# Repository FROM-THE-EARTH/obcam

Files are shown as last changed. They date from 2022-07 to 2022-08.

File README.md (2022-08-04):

# obcam

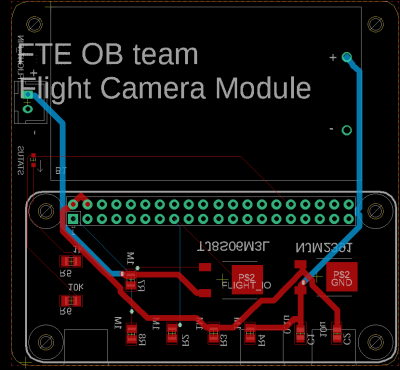
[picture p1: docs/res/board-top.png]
board


`obcam` is the flight camera module and program for the OB team rocket in NSE 2022. See [the site](https://FROM-THE-EARTH.github.io/obcam/) for details.

## Install

After configuration for network connection and installation of `git` and `pip`, run

```bash
python -m pip install git+https://github.com/FROM-THE-EARTH/obcam.git
```

## Install and Activate the flight camera mode

After configuration for network connection and installation of `git`, run

```bash
git clone https://github.com/FROM-THE-EARTH/obcam.git
cd obcam

# After filling out and confirming the glm.py
# See the documentation for detail of the settings.
sudo ./install.sh
```

## Scripts

Scripts in the `scripts` directory may be useful if you want some small operations like installing just `obcam`, activate the flight camera mode, or deactivate the flight camera mode. See [the site](https://FROM-THE-EARTH.github.io/obcam/scripts/) for more information.

**`install.sh`**

This script installs `obcam` and activates the flight camera mode simultaneously.

**`scripts/activate_flightcam.sh`**

This script activates the flight camera mode of the `obcam`. In the flight camera mode, the program of the `obcam` run automatically when booting.

**`scripts/deactivate_flightcam.sh`**

This script deactivates the flight camera mode.

**`scripts/expand_swap.sh`**

This script expands size of the swap file `/var/swap`. In the default setting, size of the swap will be changed to 2048 MB.

**`scripts/install_obcam.sh`**

This script installs the `obcam` module using `pip`. Note that `pip` should be installed before executing this script.

**`scripts/install_pip.sh`**

This script installs `pip`. Note that `pip` could be not installed yet right after the first booting. Thus, this script might be useful in the situation.

**`scripts/uninstall_obcam.sh`**

This script uninstalls the `obcam` module using `pip`.

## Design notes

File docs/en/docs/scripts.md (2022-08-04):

# Scripts

There are some executable shell scripts in the repository. You can run the scripts if downloading the repository to local. In many cases, you should execute the scripts as the root user.

## `install.sh`

This script installs `obcam` and activates the flight camera mode simultaneously. This script is executed using other scripts below, so you should not delete other scripts. This script requires network connection.

```bash
sudo ./install.sh
```

## `scripts/activate_flightcam.sh`

This script activates the flight camera mode.

```bash
sudo scripts/activate_flightcam.sh
```

## `scripts/deactivate_flightcam.sh`

This script deactivates the flight camera mode.

```bash
sudo scripts/deactivate_flightcam.sh
```

**`scripts/expand_swap.sh`**

This script expands size of the swap file `/var/swap`. In the default setting, size of the swap will be changed to 2048 MB.

```bash
sudo scripts/expand_swap.sh
```

You can change the swap size specifying value of the environment variable `SWAPSIZE`:

```bash
# Change to 1024 MB.
sudo SWAPSIZE=1024 scripts/expand_swap.sh
```

## `scripts/install_obcam.sh`

This script just installs `obcam` using `pip`, but doesn't activate the flight camera mode. This script requires network connection.

```bash
sudo scripts/install_obcam.sh
```

## `scripts/install_pip.sh`

This script installs `pip`. This script requires network connection.

```bash
sudo scripts/install_pip.sh
```

## `scripts/uninstall_obcam.sh`

This script uninstalls `obcam` using `pip`.

```bash
sudo scripts/uninstall_obcam.sh
```

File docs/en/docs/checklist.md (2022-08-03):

# Checklist

## Advance Preparation

- [ ] Make more than 2 SD cards Raspberry Pi OS Lite (32bit), referencing [the section](./setup.md#setup-of-the-os).
- [ ] Connect a monitor and keyboard to the Raspberry Pi.
- [ ] Boot the Raspberry Pi.
- [ ] Configure the keyboard setting.
- [ ] Configure the system settings using `raspi-config`, referencing [the section](./setup.md#essential-system-setttings-in-raspi-config).
    - [ ] WiFi setting for network connection.
    - [ ] Enabling legacy camera support.
- [ ] Install `git`:
    ```bash
    sudo apt update
    sudo apt install -y git
    ```
- [ ] Clone the `obcam` repository:
    ```bash
    git clone https://github.com/FROM-THE-EARTH/obcam.git
    cd obcam
    ```
- [ ] Confirm `glm.py` in the repository and change the content if necessary.
    ```bash
    # Confirm the content
    less glm.py

    # Change the content
    vi glm.py
    ```
- [ ] Install `obcam` and activate the flight camera mode:
    ```bash
    sudo ./install.sh
    ```
- [ ] Reboot the system:
    ```bash
    sudo reboot
    ```
- [ ] Check the LED is blinking (which means the program waits for connection of a flight pin). If the LED is blinking, then all preparation is done. Otherwise, connect a monitor and keyboard to the Raspberry Pi and view log output from the program. For more log output, you can change value of the parameter `log_level` to `logging.DEBUG` in `/usr/local/src/obcam/glm.py`:
    ```bash
    sudo vi /usr/local/src/obcam/glm.py

    # in the file
    #
    # ...
        - log_level=logging.INFO,
        + log_level=logging.DEBUG,
    ```

## In a rocket range

- [ ] Connect a Raspberry Pi which is setup already, flight pin cable, and 9V battery to the board.
- [ ] Confirm the LED is blinking. If the flight pin is already connected, the LED doesn't blink but is turned off. If the LED is being turned off dispite the flight pin is disconnected, connect a monitor and keyboard to the Raspberry Pi and view log output from the program. If the camera is not detected, try to enable legacy camera support referencing [the section](./setup.md#enabling-legacy-camera-support) and reconnect camera cable.
- [ ] If the program is executed successfully, put the board in to a plastic bag.
- [ ] Close up the zipper of the plastic bag using curing tape.
- [ ] Put the plastic bag in to another platic bag and close up the zipper again.
- [ ] Put some block of styrofoam in to the nose corn.
- [ ] Put the camera in to the nose cone and fix the camera using curing tape.
- [ ] Put the plastic bag in to the nose corn.
- [ ] Connect the flight pin cable to the cable for the main board.
- [ ] Connect the flight pin.
- [ ] If you need, activate certain [command](./flightcam.md#commands).

## After collecting the body

- [ ] Remove the SD card from the Raspberry Pi and clean the SD card.
- [ ] Insert the SD card to your PC.
- [ ] Extract the movie file and log file from the SD, referencing [the section](./flightcam.md#extract-data-from-sd-cards).
- [ ] Confirm the movie and log.

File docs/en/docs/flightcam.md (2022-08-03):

# Flight Camera

## Assembly

If you finish activation of the flight camera mode referencing the [page](./setup.md), you can go forward to the next step, assembly of the module. In this section, details of components and their assembly are explained.

### Board Overview

The figure below is a board of the flight camera module. The module has some features:

- **Status LED** tells status of the program in the flight camera mode.
- **XH pin socket** is the interface to a flight pin.

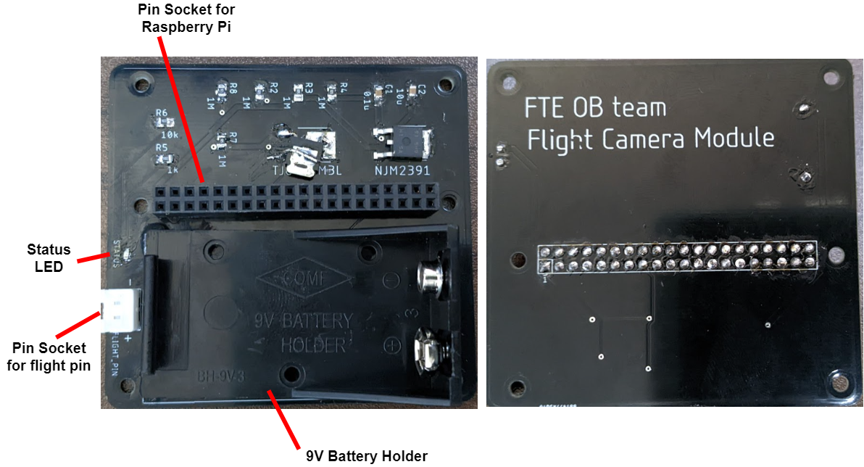
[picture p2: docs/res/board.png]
board


### Raspberry Pi Zero

The below picture is of a Raspberry Pi Zero. Raspberry Pi Zero has 40 of GPIO pins and some interfaces, e.g. HDMI, USB and Raspberry Pi Camera. It is recommended to connect to a monitor and keyboard when you setup a Raspberry Pi.

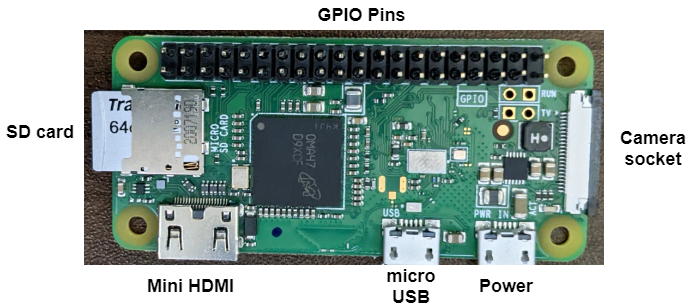
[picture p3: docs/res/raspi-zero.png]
raspi-zero


!!!info "Setup a Raspberry Pi Zero without a monitor"
    There is a way to setup a Raspberry Pi Zero without a monitor, but it is not recommended because it has more steps for setup and you cannot get any signals if there is something wrong.

### Connecting a Camera

1. Prepare a Raspberry Pi Camera and flexible cable for Raspberry Pi Zero. Note that the cable for Raspberry Pi Zero is not same as one of Type A or B.
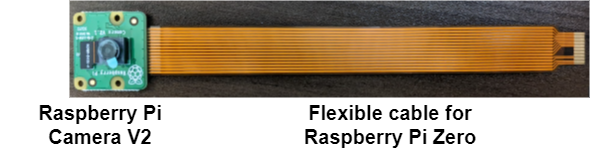
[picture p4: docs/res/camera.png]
camera
   

2. Raspberry Pi Zero has a camera socket and its stopper (black part of the bottom). Put the stopper down to insert the cable.<br>
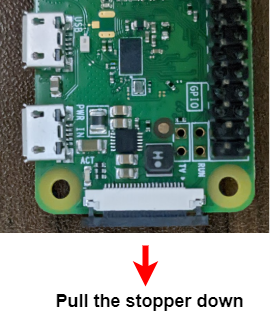
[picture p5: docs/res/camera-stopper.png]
camera-stopper
   

3. Insert the cable into the socket and put the stopper in to fix the cable.
   connecting-camera

### Board Assembly

1. Insert GPIO pins into the pin socket on the board.
2. Connect a flight pin cable to the XH socket.
3. Put in a 9V battery to the battery holder. And then, the Raspberry Pi starts to boot.
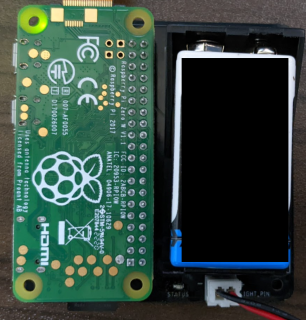
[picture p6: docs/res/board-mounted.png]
board-mounted


## Flow of the program

### Operations

1. Program starts at booting.
2. Status LED blinks until the flight pin is connected.
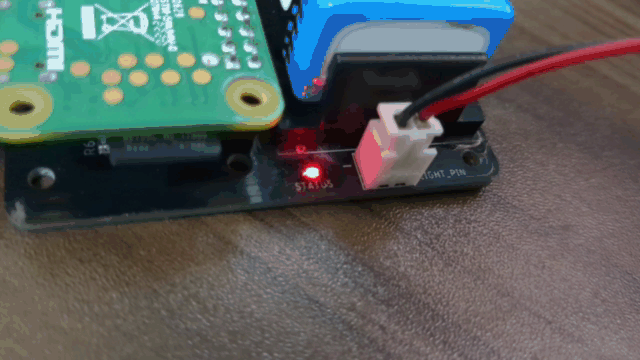
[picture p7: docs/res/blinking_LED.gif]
blinking_LED
    
3. After the flight pin is connected, the status LED is turned off until the flight pin is to be disconnected.
4. When the flight pin is disconnected, the stauts LED is turned on and recording starts.
5. Observing if any commands occur while recording.
6. When the time elapses to the value of `timeout` or a command is detected, recording stops.
7. If the setting is configured, the system is automatically shutted down.

### Commands

There are some commands for users to operate state of the program.

| name | condition | description |
|:---:|:---:|:---|
| NULL | --- | No commands are activated. |
| RESTART | Flight pin connection in more than `threshold_restart` seconds. | Program will stop recording and restart from the begging. Parameter `threshold_restart` can be set in `glm.py`, defaults 5 seconds. |
| EXIT | Flight pin connection in less than `threshold_exit` seconds, and then disconnection in more than `threshold_exit` seconds. | Program will stop recording and exit immediately without shutting down. Parameter `threshold_exit` can be set in `glm.py`, defaults 2 seconds. |

### Flowchart

Characters in red in the flowchart below are parameters in the application. For more information, see [Setting](./setting.md).

flowchart

## Outputs

The flight camera application outputs two kinds of files, one is a movie file and the other is a log file.

### Movie Files

Movie files are the main outputs of the application. You can specify path to a movie file before activating the flight camera mode, by writing the path to `glm.py`. See [Setting](./setting.md#filemov) for details.

In the default setting, the format of movie files is `.h264`. This format could not be played in your favorite movie player. It is recommended using [VLC media player](https://www.videolan.org/vlc/index.ja.html) for playing the format of movies. However, there can exist block noise when playing `.h264` videos, so it might be ideal that you convert `.h264` format to `.mp4` (which is possible using like [the site](https://anyconv.com/ja/h264-to-mp4-konbata/)).

### Log Files

Log files are useful to analysis state of the application, especially during debug. You can also specify path to a log file before activating the flight camera mode. See [Setting](./setting.md#filelog) for more information.

The log level of the application can be changed in `glm.py`. You can specify `logging.DEBUG` as parameter `log_level` to output verbose log for debugging.

Below is an example of the log output.

```log
[2022-08-02 03:59:53,126] [INFO] Start the Flight camera mode. Setting; glm_name: main, timeout: 210.0, pin_flight: 22, pin_led: 12, file_mov: mov-220802-035953.h264, file_log: mov-220802-035953.log, parent_dir: None, resolution: (1920, 1080), framerate: 30, interval: 0.1, led_blink_freq: 2.0, log_level: 20, check_waiting_time: False
[2022-08-02 03:59:53,218] [INFO] Waiting a flight pin to be connected...
[2022-08-02 04:00:01,074] [INFO] Detected that the flight pin was connected.
[2022-08-02 04:00:01,075] [INFO] Wating the flight pin to be disconnected...
[2022-08-02 04:00:03,034] [INFO] Detected that the flight pin was disconnected.
[2022-08-02 04:00:03,034] [INFO] Start recording.
[2022-08-02 04:03:33,151] [INFO] Stop recording.
```

### Extract data from SD cards

Your Windows couldn't recognize data in SD cards used in Raspberry Pi because of difference of formats. Thus, you should do unusual operation to extract the data.

**Use 3rd-party applications**

There are some applications that can read data in ext file systems like Raspberry Pi. You can pick favorite one from the list below:

- [extFS for Windows](https://www.paragon-software.com/business/extfs-for-windows/)
- [Linux Reader](https://www.diskinternals.com/linux-reader/)

**Transfer via HTTP**

If you have another Raspbery Pi, which is not broken and whose WiFi setting (tethering is recommended) is already done, you can insert the SD card to the Raspberry Pi and transfer data via HTTP communication.

1. Enable network connection of a Raspberry Pi. If network setting is not done yet, configure referencing [the section](./setup.md#wifi-setting).
2. Confirm IP address of the Raspberry Pi:
    ```bash
    ip a

    # Example of output
    # ...
    # 2: wlan0: <BROADCAST,MULTICAST,UP,LOWER_UP> mtu 1500 qdisc mq state UP group default qlen 1000
    # link/ether ff:ff:ff:ff:ff:ff brd ff:ff:ff:ff:ff:ff
    # inet 192.168.x.x/24 brd 192.168.x.255 scope global noprefixroute eth0
    #       ↑ this is the IP address.
    ```
3. Change the working directory to directory which has files you want to send.
    ```bash
    cd [/path/to/directory]
    # e.g. cd /
    ```
4. Start HTTP server specifying the IP address.
    ```bash
    # Change the IP address to one of your environment.
    sudo python -m http.server -b 192.168.x.x 80
    ```
5. Open a browser in your smart phone or PC in the same network as the Raspbery Pi.
6. Enter the URL:
    ```
    # Change the IP address to one of your environment.
    # Change the file name to one you want to send.
    http://192.168.x.x/[file_name]
    ```

**Transfer via SSH**

If you have another Raspbery Pi, which is not broken and whose WiFi setting (tethering is recommended) is already done, you can insert the SD card to the Raspberry Pi and transfer data via SSH communication.

1. Enable network connection of a Raspberry Pi. If network setting is not done yet, configure referencing [the section](./setup.md#wifi-setting).
2. Enable the SSH server:
    ```bash
    sudo raspi-config
    # 1. Select [Interface Options]
    # 2. Select [SSH]
    # 3. Select [Yes]
    ```
3. Confirm IP address of the Raspberry Pi:
    ```bash
    ip a

    # Example of output
    # ...
    # 2: wlan0: <BROADCAST,MULTICAST,UP,LOWER_UP> mtu 1500 qdisc mq state UP group default qlen 1000
    # link/ether ff:ff:ff:ff:ff:ff brd ff:ff:ff:ff:ff:ff
    # inet 192.168.x.x/24 brd 192.168.x.255 scope global noprefixroute eth0
    #       ↑ this is the IP address.
    ```
4. Open a terminal (PowerShell in Windows) in your PC in the same network as the Raspberry Pi, and run the command:
    ```bash
    # Change the IP address to one of your environment.
    # Change paths in remote and local to ones you want to send and received.
    scp obteam@192.168.x.x:/path/to/file /local/path/to/file

    # Enter passphrase of the Raspberry Pi.
    ```

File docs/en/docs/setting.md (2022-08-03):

# Setting

## gileum file

gileum files are kinds of setting files of the application. In a gileum file, an object of the `OBCamGileum` should be created. The default gileum file is prepared [in the repository](https://github.com/FROM-THE-EARTH/obcam/blob/main/glm.py). If necessary, you can change the content of the gileum file and apply the setting when executing the flight camera application.

## `OBCamGileum`

This class is the setting class of the application. You should only instantiate the class giving the parameters below.

### `timeout`

Length of recording time.

### `pin_flight`

Pin number for a flight pin, defaults `22`.

### `pin_led`

Pin number for a status LED, defaults `12`.

### `file_mov`

Path to new video file, defaults `None`.

### `file_log`

Path to new log file, defaults `None`.

### `parent_dir`

Path to the parent directory of output files, defaults `None`. If a specfied directory doesn't exist, the program automatically create the repository.

### `resolution`

Resolution of the video to be recorded, defaults `(1920, 1080)`. You cannot make the value greater than the default value, because `(1920, 1080)` is about maximum value.

### `framerate`

Framerate of the video to be recorded, defaults `30`. You cannot make the value greater than the default value, because `30` fps is about maximum value.

### `interval_recording`

Wating time for recording, `0.1`.

### `led_blink_freq`

Frequency of LED blinking, defaults `2.`.

### `log_level`

Log level used in the application, defaults `logging.INFO` (`20`).

### `check_waiting_time`

If making log outputs during waiting time for disconnection of the flight pin or not, defaults `False`.

### `interval_waiting_time`

Interval of waiting time until the flight pin is disconnected, defaults `0.1`. This parameter doesn't valid when the parameter `check_waiting_time` is `False`.

### `shutdown_after_recording`

If shutting down the system after recording or not, defaults `True`.

### `interval_watching`

Interval of watching processes in other threads, defaults `0.1`.

### `threshold_restart`

Time threshold of waiting time to activate the command `RESTART`, defaults `5.`. The command `RESTART` is activated if the flight pin is connected again for more than `threshold_restart` seconds during recording.

### `threshold_exit`

Time threshold of waiting time to activate the command `EXIT`, defaults `2.`. The command `EXIT` is activated if the flight pin is connected for less than `threshold_exit` seconds and disconnected again for more than `threshold_exit` seconds during recording.

## Examples

```python
import logging
from obcam import OBCamGileum

glm = OBCamGileum(
    # Make the timeout shorter for tests.
    timeout=10,

    # Change path to the movie file.
    file_mov="test.h254",

    # Change path to the log file.
    flie_log="test.log",

    # Set the parent directory of the output files.
    parent_dir="/obcam-out"

    # Make the frequency smaller.
    led_blink_freq=1.,

    # Make verbose log outputs for tests.
    log_level=logging.DEBUG,

    # Observe waiting time until the flight pin is disconnected.
    check_waiting_time=True,

    # Use the default settings.
    # To use defualt values, you don't have to give corresponding arguments.
    pin_flight=22,
    pin_led=12,
    resolution=(1920, 1080),
    framerate=30,
    interval_recording=0.1,
    interval_waiting_time=0.1,
    shutdown_after_recording=True,
    interval_watching=0.1,
    threshold_restart=5.,
    threshold_exit=2.,
)
```

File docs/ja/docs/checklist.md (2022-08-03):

# チェックリスト

## 事前準備

- [ ] [こちらのセクション](./setup.md#os)を参考にして Raspberry Pi OS Lite (32bit) のイメージが書き込まれた SD カードを3個以上準備しておきます。
- [ ] Raspberry Pi にモニターとキーボードを接続します。
- [ ] Raspberry Pi を起動します。
- [ ] キーボード設定を行います。
- [ ] [こちらのセクション](./setup.md#raspi-config)を参考にして `raspi-config` を使ったシステム設定を行います。
    - [ ] WiFi 設定
    - [ ] 「legacy camera support」の有効化
- [ ] `git` のインストールを行います。
    ```bash
    sudo apt update
    sudo apt install -y git
    ```
- [ ] `obcam` リポジトリのダウンロードを行います。
    ```bash
    git clone https://github.com/FROM-THE-EARTH/obcam.git
    cd obcam
    ```
- [ ] リポジトリ下の `glm.py` を確認し、必要があれば編集します。
    ```bash
    # Confirm the content
    less glm.py

    # Change the content
    vi glm.py
    ```
- [ ] `obcam` のインストールとフライトカメラモードの有効化を行います。
    ```bash
    sudo ./install.sh
    ```
- [ ] Raspberrry Pi を再起動します。
    ```bash
    sudo reboot
    ```
- [ ] LED の点滅を確認します（LED の点滅はフライトピンの接続待ち状態を意味します）。もし LED が点滅している場合は全ての事前準備が完了した状態です。そうでなければ、モニターとキーボードを Raspberrry Pi に接続し、プログラムのログ出力を確認してください。詳細なログ出力を行いたい場合は `/usr/local/src/obcam/glm.py` 内の `log_level` パラメータを `logging.DEBUG` に変更します：
    ```bash
    sudo vi /usr/local/src/obcam/glm.py

    # in the file
    #
    # ...
        - log_level=logging.INFO,
        + log_level=logging.DEBUG,
    ```

## 射場にて

- [ ] セットアップされた Raspberrry Pi とフライトピン用ケーブル、9V バッテリーを基板に接続します。
- [ ] ステータス LED の点滅を確認します。もしフライトピンが接続されている場合は、LED は点滅せず消灯状態になります。フライトピンが接続されているにも関わらず LED が消灯している場合は、モニターとキーボードを Raspberrry Pi  に接続してログ出力を確認してください。もしカメラの接続が検知されていなかった場合は、[こちらのセクション](./setup.md#legacy-camera-support)を参考にして「legacy camera support」を有効化するとともに、カメラ用ケーブルを再接続してください。
- [ ] プログラムが正常に起動している場合、基板をジップロックに入れます。
- [ ] 養生テープでジッパー部分を閉めます。
- [ ] もう1つのジップロックに基板を入れたジップロックを入れ、再度養生テープでジッパー部分を閉めます。
- [ ] 発泡スチロールのブロックをノーズコーンに入れます。
- [ ] カメラをノーズコーン内に入れ、養生テープで固定します。
- [ ] 基板を入れたジップロックをノーズコーンに入れます。
- [ ] カメラ基板から出ているフライトピン用ケーブルをメイン電装のフライトピン用ケーブルと接続します。
- [ ] フライトピンを接続します。
- [ ] 必要があれば[コマンド](./flightcam.md#_8)を実行します。

## 回収後

- [ ] SD カードを Raspberrry Pi から取り出し汚れをふき取ります。
- [ ] PC に SD カードを差し込みます。
- [ ] [こちらのセクション](./flightcam.md#sd)を参考にして動画ファイルとログファイルを取り出します。
- [ ] 動画とログを確認します。

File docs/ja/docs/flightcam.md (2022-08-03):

# フライトカメラ

## 組み立て

[こちらのページ](./setup.md)を参考にしてフライトカメラモードを有効化し終わったら、基板の組み立てを行います。このセクションでは部品とそれらの組み立てについて説明します。

### 基板の概要

下図はフライトカメラモジュールの基板です。このモジュールには以下のような特徴があります：

- **ステータス LED** でフライトカメラモードでのプログラムの状態を把握することが出来ます。
- **XH ピンソケット** はフライトピン用のインターフェースになっています。

board

### Raspberry Pi Zero

Raspberrry Pi Zero （下図）は 40 個の GPIO ピンと HDMI や USB 、Raspberrry Pi Camera のようなインターフェースを持っています。Raspberrry Pi をセットアップする場合は、モニターとキーボードを接続することを推奨します。

raspi-zero

!!!info "モニターなしでの Raspberry Pi Zero のセットアップ"
    Raspberry Pi Zero にはモニターなしでセットアップを行う方法があります。しかし、セットアップ方法が複雑化することと問題が発生した場合に原因の特定が難しいことから、モニターを接続したうえでセットアップすることをおすすめします。

### カメラの接続

1. Raspberry Pi Camera と Raspberry Pi Zero 用のフレキシブルケーブルを準備します。Raspberry Pi Zero 用のフレキシブルケーブルは Type A や Type B 用のものとは異なることに注意してください。
   camera

2. Raspberry Pi Zero にはカメラソケットとそのストッパー（下図の黒い部分）が取り付けられています。ケーブルを挿入するためにストッパーを引き出します。<br>
   camera-stopper

3. フレキシブルケーブルを挿入し、ストッパーを押し込んでケーブルを固定します。
   connecting-camera

### モジュールの組み立て

1. Raspberry Pi Zero の GPIO ピンをピンソケットに挿入します。
2. フライトピン用ケーブルを XH ピンソケットに接続します。
3. 9V バッテリーをバッテリーホルダー内に入れます。すると、Raspberry Pi Zero が起動されます。
board-mounted

## プログラムの流れ

### プログラム内での操作

1. 起動とともにプログラムが実行されます。
2. フライトピンが接続されるまでステータス LED が点滅します。
    blinking_LED
3. フライトピンが接続されると、フライトピンが離脱するまでステータス LED が消灯します。
4. フライトピンが離脱すると、ステータス LED が点灯し、録画が開始されます。
5. 録画中にコマンドが有効化するかどうか監視します。
6. giluem ファイル内の `timeout` パラメータに設定した秒数だけ経過するかコマンドが検知されると、録画が停止されます。
7. コマンドが有効化されず `shutdown_after_recording` が `True` である場合、システムが自動シャットダウンされる。

### コマンド

プログラムの状態を操作するために、いくつかのコマンドが用意されています。

| 名前 | 発動条件 | 概要 |
|:---:|:---:|:---|
| NULL | --- | コマンドが1つも有効化されていない状態。 |
| RESTART | フライトピンが接続されて `threshold_restart` 秒以上が経過する. | 録画を停止し、直ちにプログラムを再起動する。`threshold_restart` パラメータは `glm.py` 内で設定可能で、デフォルトは5秒。 |
| EXIT | フライトピンが接続されて `threshold_exit` 秒以内に再度フライトピンが離脱し、その後 `threshold_exit` 秒以上経過する。 | 録画を停止し、シャットダウンせずにプログラムを終了する。`threshold_exit` パラメータは `glm.py` 内で設定可能で、デフォルトは2秒。 |

### フローチャート

フローチャート内の赤字はパラメータの名前です。詳細については[設定](./setting.md)を参照してください。

flowchart

## 出力

フライトカメラのプログラムは2種類のファイルを出力します。1つは動画ファイルであり、もう1つはログファイルです。

### 動画ファイル

動画ファイルはプログラムが出力する最も重要なファイルです。フライトカメラモードの有効化前に `glm.py` にて動画ファイルのパスを指定することが出来ます。詳細については[設定](./setting.md#filemov)を参照してください。

デフォルトの設定では、出力される動画ファイルのフォーマットは `.h264` です。動画プレイヤーによっては、このフォーマットの動画を再生できない可能性があります。このフォーマットの動画の再生には [VLC media player](https://www.videolan.org/vlc/index.ja.html) がおすすめです。しかし、 VLC で `.h264` のフォーマットの動画を再生する場合にはブロックノイズが発生することがあるため、`.h264` から `.mp4` へ変換すると良いです（例えば[こちらのサイト](https://anyconv.com/ja/h264-to-mp4-konbata/)などで行えます)。

### ログファイル

ログファイルはアプリケーションの状態を解析する際に有用です。ログファイルのパスも `glm.py` にて指定できますが、詳細については[設定](./setting.md#filelog)を参照してください。

`glm.py` ではアプリケーションのログレベルも指定することが出来ます。詳細なログの出力を行うためには `log_level` パラメータに `logging.DEBUG` を指定します。

以下にログ出力の例を示します：

```log
[2022-08-02 03:59:53,126] [INFO] Start the Flight camera mode. Setting; glm_name: main, timeout: 210.0, pin_flight: 22, pin_led: 12, file_mov: mov-220802-035953.h264, file_log: mov-220802-035953.log, parent_dir: None, resolution: (1920, 1080), framerate: 30, interval: 0.1, led_blink_freq: 2.0, log_level: 20, check_waiting_time: False
[2022-08-02 03:59:53,218] [INFO] Waiting a flight pin to be connected...
[2022-08-02 04:00:01,074] [INFO] Detected that the flight pin was connected.
[2022-08-02 04:00:01,075] [INFO] Wating the flight pin to be disconnected...
[2022-08-02 04:00:03,034] [INFO] Detected that the flight pin was disconnected.
[2022-08-02 04:00:03,034] [INFO] Start recording.
[2022-08-02 04:03:33,151] [INFO] Stop recording.
```

### SD カードからのデータの取り出し

Windows ではそのフォーマットの違いから Raspberry Pi で使用した SD カード内のデータを認識できない可能性があります。以下では Raspberrry Pi に使用した SD カード内のデータを取り出すいくつかの方法を説明します。

**3rd パーティー製のアプリケーションの利用**

ext ファイルシステムを読み込むことが出来る以下のようなアプリケーションを使用すると、SD カード内のデータを取り出すことが出来ます：

- [extFS for Windows](https://www.paragon-software.com/business/extfs-for-windows/)
- [Linux Reader](https://www.diskinternals.com/linux-reader/)

**HTTP で送信する**

故障していない Raspberrry Pi がある場合、その Raspberrry Pi で WiFi 設定がなされていれば、SD カードをその Raspberrry Pi に挿入し、HTTP 通信によってデータを転送することが出来ます。

1. Raspberrry Pi のネットワーク接続を有効にします。もしネットワーク設定がなされていない場合は、[こちらのセクション](./setup.md#wifi)を参考にして設定を行ってください。
2. Raspberrry Pi の IP アドレスを確認します。
    ```bash
    ip a

    # Example of output
    # ...
    # 2: wlan0: <BROADCAST,MULTICAST,UP,LOWER_UP> mtu 1500 qdisc mq state UP group default qlen 1000
    # link/ether ff:ff:ff:ff:ff:ff brd ff:ff:ff:ff:ff:ff
    # inet 192.168.x.x/24 brd 192.168.x.255 scope global noprefixroute eth0
    #       ↑ this is the IP address.
    ```
3. カレントディレクトリを送信したいファイルがあるディレクトリに移します。
    ```bash
    cd [/path/to/directory]
    # e.g. cd /
    ```
4. 先ほどの IP アドレスを指定して HTTP サーバーを起動します。
    ```bash
    # Change the IP address to one of your environment.
    sudo python -m http.server -b 192.168.x.x 80
    ```
5. Raspberrry Pi と同じネットワーク内にあるスマートフォンや PC 上でブラウザを起動します。
6. 以下のような URL を入力してファイルをダウンロードします。
    ```
    # Change the IP address to one of your environment.
    # Change the file name to one you want to send.
    http://192.168.x.x/[file_name]
    ```

**SSH で送信する**

故障していない Raspberrry Pi がある場合、その Raspberrry Pi で WiFi 設定がなされていれば、SD カードをその Raspberrry Pi に挿入し、SSH を利用してデータを転送することが出来ます。

1. Raspberrry Pi のネットワーク接続を有効にします。もしネットワーク設定がなされていない場合は、[こちらのセクション](./setup.md#wifi)を参考にして設定を行ってください。
2. SSH サーバーを有効化します：
    ```bash
    sudo raspi-config
    # 1. Select [Interface Options]
    # 2. Select [SSH]
    # 3. Select [Yes]
    ```
3. Raspberrry Pi の IP アドレスを確認します。
    ```bash
    ip a

    # Example of output
    # ...
    # 2: wlan0: <BROADCAST,MULTICAST,UP,LOWER_UP> mtu 1500 qdisc mq state UP group default qlen 1000
    # link/ether ff:ff:ff:ff:ff:ff brd ff:ff:ff:ff:ff:ff
    # inet 192.168.x.x/24 brd 192.168.x.255 scope global noprefixroute eth0
    #       ↑ this is the IP address.
    ```
4. Raspberrry Pi と同じネットワーク上にある PC でターミナル（Windows の場合は PowerShell）を開き、以下のコマンドを実行します。
    ```bash
    # Change the IP address to one of your environment.
    # Change paths in remote and local to ones you want to send and received.
    scp obteam@192.168.x.x:/path/to/file /local/path/to/file

    # Enter passphrase of the Raspberry Pi.
    ```

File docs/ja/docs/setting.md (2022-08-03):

# 設定

## gileum ファイル

gileum ファイルはこのアプリケーションの設定ファイルです。 gileum ファイル内には1つの `OBCamGileum` オブジェクトが生成されている必要があります。デフォルトの gileum ファイルはリポジトリ下に用意されています。必要であれば、フライトカメラモードの有効化前にデフォルトの gileum ファイルを編集して、パラメーターの変更を反映させることが出来ます。

## `OBCamGileum`

このアプリケーションの設定用クラスです。以下のパラメータが指定されたオブジェクトを生成する必要があります。

### `timeout`

録画時間の長さ（秒）。

### `pin_flight`

フライトピンのピン番号（BCM）。デフォルトは `22`。

### `pin_led`

ステータス LED 用のピン番号（BCM）。デフォルトは `12`。

### `file_mov`

録画されるビデオファイルのパス。デフォルトは `None`。

### `file_log`

出力されるログファイルのパス。デフォルトは `None`。

### `parent_dir`

出力されるファイルの親ディレクトリのパス。デフォルトは `None`。もし指定されたディレクトリが存在しない場合は実行時に作成されます。

### `resolution`

録画されるビデオの解像度。デフォルトは `(1920, 1080)`。  `(1920, 1080)` は最大の解像度であるため、これ以上の値を指定することは出来ません。

### `framerate`

録画されるビデオのフレームレート（fps）。デフォルトは `30`。`30` fps が最大値であるので、これ以上の値を指定することが出来ません。

### `interval_recording`

録画時の待機時間（秒）。デフォルトは `0.1`。

### `led_blink_freq`

LED 点滅時の周波数（Hz）。デフォルトは `2.`。

### `log_level`

出力するログのログレベル。デフォルトは `logging.INFO` (`20`)。

### `check_waiting_time`

フライトピン離脱までの待機時にログを出力するかどうかの真偽値。デフォルトは `False`。

### `interval_waiting_time`

フライトピン離脱までの待機時のインターバル（秒）。デフォルトは `0.1`。このパラメータは `check_waiting_time` が `False` の場合は無効。

### `shutdown_after_recording`

録画終了後にシャットダウンするかどうかの真偽値。デフォルトは `True`。

### `interval_watching`

他スレッドでの状態監視プロセスのインターバル（秒）。デフォルトは `0.1`。

### `threshold_restart`

`RESTART` コマンドを有効にする時間の閾値（秒）。デフォルトは `5.`。`RESTART` コマンドは、録画中にフライトピンが再度接続され `threshold_restart` に設定した秒数だけ経過した場合に有効化される。

### `threshold_exit`

`EXIT` コマンドを有効にする時間の閾値（秒）。デフォルトは `2.`。`EXIT` コマンドは、録画中にフライトピンが再度接続され、 `threshold_exit` に設定した秒数が経過する前に再度抜かれ、その状態で `threshold_exit` に設定した秒数が経過した際に有効化される。

## 例

```python
import logging
from obcam import OBCamGileum

glm = OBCamGileum(
    # Make the timeout shorter for tests。
    timeout=10,

    # Change path to the movie file。
    file_mov="test。h254",

    # Change path to the log file。
    flie_log="test。log",

    # Set the parent directory of the output files。
    parent_dir="/obcam-out"

    # Make the frequency smaller。
    led_blink_freq=1。,

    # Make verbose log outputs for tests。
    log_level=logging。DEBUG,

    # Observe waiting time until the flight pin is disconnected。
    check_waiting_time=True,

    # Use the default settings。
    # To use defualt values, you don't have to give corresponding arguments。
    pin_flight=22,
    pin_led=12,
    resolution=(1920, 1080),
    framerate=30,
    interval_recording=0。1,
    interval_waiting_time=0。1,
    shutdown_after_recording=True,
    interval_watching=0。1,
    threshold_restart=5。,
    threshold_exit=2。,
)
```

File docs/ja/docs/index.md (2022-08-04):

# obcam

board

`obcam` は能代宇宙イベント2022に参加する FTE OB チームのフライトカメラモジュールおよびプログラムです。詳細については[こちらのサイト](https://FROM-THE-EARTH.github.io/obcam/ja/)を参照してください。

## インストール

ネットワーク設定と `git` および `pip` のインストールが済んだうえで、以下のコマンドを実行します：

```bash
python -m pip install git+https://github.com/FROM-THE-EARTH/obcam.git
```

## インストールおよびフライトカメラモードの有効化

ネットワーク設定と `git` のインストールが済んだうえで、以下のコマンドを実行します：

```bash
git clone https://github.com/FROM-THE-EARTH/obcam.git
cd obcam

# glm.py に設定値を記入した後に実行
# 設定の詳細についてはドキュメントを参照
sudo ./install.sh
```

## スクリプト

`scripts` ディレクトリ内のスクリプトは `obcam` のインストールやフライトカメラの有効化・無効化などの比較的小さな処理を行う際に便利です。詳細については[こちらのページ](https://FROM-THE-EARTH.github.io/obcam/scripts/)を参照してください。

**`scripts/install.sh`**

`obcam` のインストールとフライトカメラモードの有効化を同時に行うスクリプトです。

**`scripts/activate_flightcam.sh`**

`obcam` のフライトカメラモードを有効にするスクリプトです。フライトカメラモードでは、`obcam` のプログラムは起動時に自動的に実行されます。

**`scripts/deactivate_flightcam.sh`**

フライトカメラモードを無効化するスクリプトです。

**`scripts/extend_swap.sh`**

swap ファイルの容量を変更するスクリプトです。デフォルトでは 100MB から 2048 MB に変更します。

**`scripts/install_obcam.sh`**

`pip` を使って `obcam` をインストールするスクリプトです。スクリプト実行前に `pip` がインストールされている必要があります。

**`scripts/install_pip.sh`**

`pip` をインストールするスクリプトです。`pip` は最初の起動時にはインストールされていない可能性があるため、このスクリプトを使用して `pip` をインストールすることが出来ます。

**`scripts/uninstall_obcam.sh`**

`pip` を使用して `obcam` をアンインストールするスクリプトです。

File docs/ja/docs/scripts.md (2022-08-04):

# スクリプト

リポジトリ内にはいくつかの実行可能なシェルスクリプトがあります。これらはリポジトリをダウンロードした場合に使用できます。これらのスクリプトは多くの場合、ルート権限で実行される必要があります。

## `install.sh`

`obcam` のインストールとフライトカメラモードの有効化を同時に行うスクリプトです。このスクリプトは以下に挙げる他のスクリプトを組み合わせて実行されるので、他のスクリプトを削除しないよう注意してください。このスクリプトの実行にはネットワーク環境が必要です。

```bash
sudo ./install.sh
```

## `scripts/activate_flightcam.sh`

フライトカメラモードの有効化を行うスクリプトです。

```bash
sudo scripts/activate_flightcam.sh
```

## `scripts/deactivate_flightcam.sh`

フライトカメラモードの無効化を行うスクリプトです。

```bash
sudo scripts/deactivate_flightcam.sh
```

## `scripts/extend_swap.sh`

swap ファイルの容量を変更するスクリプトです。デフォルトでは 100MB から 2048 MB に変更します。

```bash
sudo scripts/expand_swap.sh
```

環境変数 `SWAPSIZE` を指定して実行することで、任意のサイズに変更できます：

```bash
# 1024 MB に変更
sudo SWAPSIZE=1024 scripts/expand_swap.sh
```

## `scripts/install_obcam.sh`

`pip` で `obcam` モジュールをインストールするスクリプトです。このスクリプトはフライトカメラモードの有効化を行いません。このスクリプトの実行にはネットワーク環境が必要です。

```bash
sudo scripts/install_obcam.sh
```

## `scripts/install_pip.sh`

`pip` のインストールを行うスクリプトです。このスクリプトの実行にはネットワーク環境が必要です。

```bash
sudo scripts/install_pip.sh
```

## `scripts/uninstall_obcam.sh`

`pip` を使用して `obcam` をアンインストールするスクリプトです。

```bash
sudo scripts/uninstall_obcam.sh
```

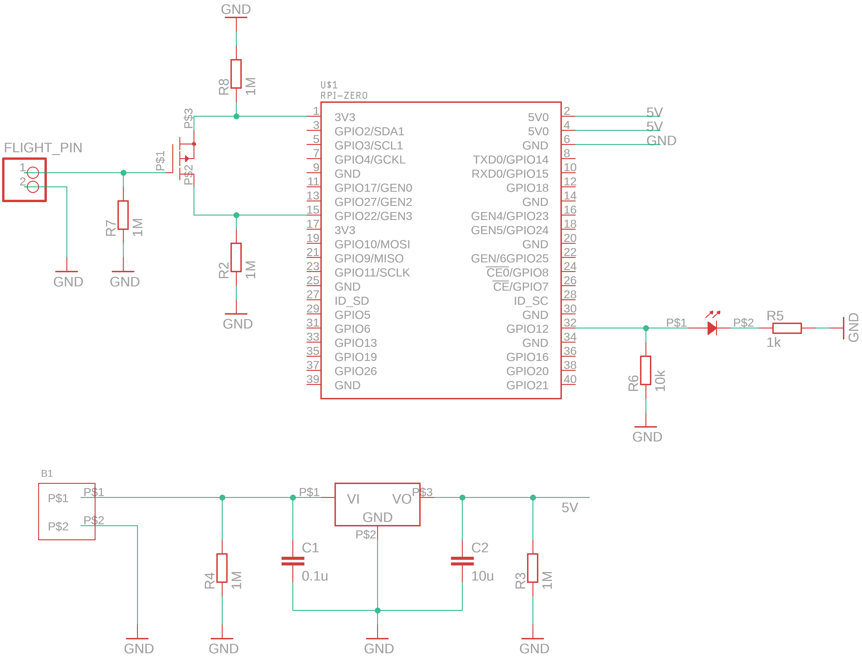
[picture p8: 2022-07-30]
eagle/img/obcam_sch.png

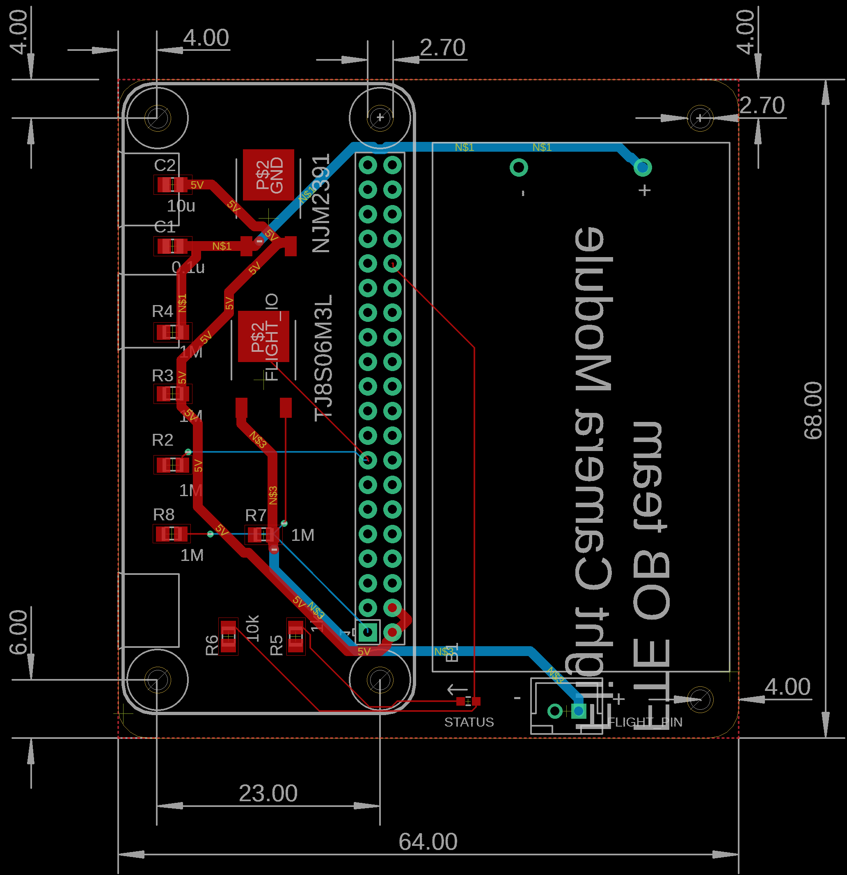
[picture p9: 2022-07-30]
eagle/img/obcam_brd.png

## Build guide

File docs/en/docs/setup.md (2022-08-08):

# Setup

## Environment

- Raspberry Pi Zero
- Raspberry Pi Camera V2
- Raspberry Pi OS Lite

## Setup of the OS

[Raspberry Pi Imager](https://www.raspberrypi.com/software/) enables brief preparation for booting Raspberry Pi OS.

**Steps for writing an OS image to micro SD**

1. Install [Raspberry Pi Imager](https://www.raspberrypi.com/software/).
2. Open Raspberry Pi Imager.
3. Select Raspberry Pi OS Lite (32bit) as OS.
4. Select a SD card the OS is written in.
5. Click *WRITE*.

raspi-imager

## Essential system setttings in `raspi-config`

Users can configure some essential settings using `raspi-config`. `raspi-config` can be executed by the command (note that it should be executed as the root user):

```bash
sudo raspi-config
```

`raspi-config` enables users to configure settings interactively, showing the interface like below:

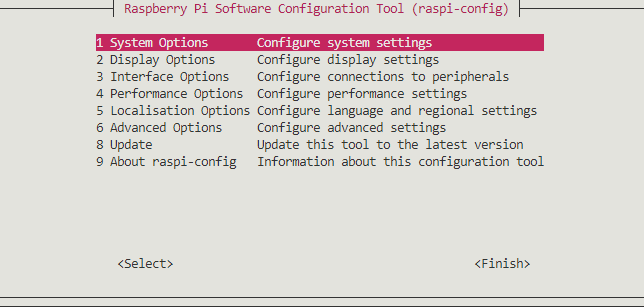
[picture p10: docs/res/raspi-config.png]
raspi-config


Users of `obcam` should configure:

1. WiFi setting for network connection.
2. Enabling legacy camera support.

!!!note "Rebooting after configuration."
    Most configuration in the `raspi-config` requires rebooting. Thus, you should reboot the system before executing the flight camera application.

### WiFi setting

In the `raspi-config` interface,

1. Select *System Options*.
2. Select *Wireless LAN*.
3. Select your country (e.g. *JP Japan*).
4. Enter SSID.
5. Enter passphrase.

!!!info "Tethering"
    Tethering by your smart phone is a good choice for WiFi access point and router. If you want to use tethering, you enter its SSID and passphrase while the setting above.

### Enabling legacy camera support

In the `raspi-config` interface,

1. Select *Interface Options*.
2. Select *Legacy Camera*.
3. Select *Yes*.
4. Select *OK*.

!!!info "Legacy camera support"
    The latest version of Raspberry Pi OS supports new camera interface using `libcamera`, so it deprecates using legacy camera support. But `picamera`, which is a Python module for using Raspberry Pi Camera and used in `obcam`, is implemented using the legacy camera interface. Therefore, you should enable it.

## Brief setup for the flight camera mode

Using this method, you can install `obcam` and activate the flight camera mode simultaneously. The brief setup gets under way using the script `install.sh` [in the repository](https://github.com/FROM-THE-EARTH/obcam/blob/main/install.sh). If you want to know the steps of activation of the flight camera mode, see the [section](#activate-the-flight-camera-mode)

First you should download the repository using `git clone` (which requires network connection):

```bash
git clone https://github.com/FROM-THE-EARTH/obcam.git
```

And then, you can execute the brief setup like below:

```bash
cd obcam
sudo ./install.sh
```

That's all setup of the flight camera mode of `obcam`. You can reboot the Raspberry Pi and run the flight camera program.

!!!info "Installation of `git`"
    If `git` is not installed in the system, you can run the commands below and install `git`:

    ```bash
    sudo apt update
    sudo apt install git
    ```

## Install only `obcam` module

`obcam` can be installed using `pip`.

```bash
pip install git+https://github.com/FROM-THE-EARTH/obcam.git
```

After the installation, you can use the `obcam` command to start the flight camera application.

!!!info "If `pip` is not installed in the system"
    Right after the first booting of Raspberry Pi, `pip` might be not installed yet. In the situation, you can install `pip` following the procedures below:

    1. Download the script to install `pip`. After the command below is executed, the script `get-pip.py` is to be downloaded in the current directory.
        ```bash
        wget https://bootstrap.pypa.io/get-pip.py
        ```
    2. Execute the script `get-pip.py`.
        ```bash
        python get-pip.py
        ```

## Activate the flight camera mode

### About the flight camera mode

In the flight camera mode, the application of the flight camera automatically starts when booting a Raspberry Pi. To activate the flight camera mode, the procedures below is required:

1. [Network and camera settings](#essential-system-setttings-in-raspi-config).
2. [Install `obcam`](#install-only-obcam-module).
3. [Writing a gileum file for the flight camera](#writing-a-gileum-file).
4. [Activate the flight camera mode](#just-activate-the-flight-camera-mode).

### Writing a gileum file

Gileum files are kinds of setting files of the application. You should write a gileum file `glm.py` before activation of the flight camera mode. The gileum file `glm.py` is in the repository, so you can overwrite the file after downloding the repository. Details of the setting parameters are written in [the page](./setting.md). But please note that the settings are already done in the `glm.py` when downloading the repository, so **you doesn't have to change the settings if there are no certain reasons**.

### Just activate the flight camera mode

Using the script `scripts/activate_flightcam.sh`, you can activate the flight camera mode. The `scripts/activate_flihgtcam.sh` is also [in the repository](https://github.com/FROM-THE-EARTH/obcam/blob/main/scripts/activate_flightcam.sh).

```bash
sudo ./scripts/activate_flightcam.sh
```

## Update `obcam`

### Update just `obcam`

You can update `obcam` following commnd:

```bash
pip install --upgrade git+https://github.com/FROM-THE-EARTH/obcam.git
```

### Update `obcam` and activate the flight camera mode

1. Delete the local repository:
    ```bash
    rm -rf obcam/
    ```
2. Follow the operations referencing [the section](#brief-setup-for-the-flight-camera-mode)

## Details of the activation

In this section, details of the activate process is described. The process is not complicated so much. The point is to update the `/etc/rc.local` file in the system. The file `/etc/rc.local` is a shell script to be executed at booting.

The script `scripts/activate_flightcam.sh` inserts the line to `/etc/rc.local`, in order to execute the `obcam` program like that:

```
# /etc/rc.local

# Some lines ...

/usr/bin/python -m obcam /usr/local/src/obcam/glm.py
exit 0
```

As you can see, the `obcam` program is executed giving the gileum file `/usr/local/src/obcam/glm.py`, which is copied when executing `scripts/activate_flightcam.sh`. Therefore, there is no effects in terms of the flight camera application if you change the content of the `glm.py` in the downloaded repository, because `obcam` refers `/usr/local/src/obcam/glm.py`. **If you want apply the change of the `glm.py` in the downloaded repository, just run `scripts/activate_flightcam.sh` again, or copy the `glm.py` to `/usr/local/src/obcam/glm.py`**.

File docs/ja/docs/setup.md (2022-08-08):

# セットアップ

## 環境

- Raspberry Pi Zero
- Raspberry Pi Camera V2
- Raspberry Pi OS Lite

## OS のセットアップ

[Raspberry Pi Imager](https://www.raspberrypi.com/software/) は Raspberry Pi OS のイメージを SD カードに簡単に書き込むことが出来るツールです。

**micro SD カードに OS イメージを書き込む手順**

1. [Raspberry Pi Imager](https://www.raspberrypi.com/software/) をインストール。
2. Raspberrry Pi Imager を起動。
3. 「Raspberry Pi OS Lite (32bit)」を OS として選択.
4. 書き込む SD カードを選択.
5. *書き込む* をクリック.

raspi-imager

## `raspi-config` によるシステム設定

`raspi-config` はシステム設定を対話的に行うことが出来る CLI ツールです。 `raspi-config` は以下のコマンドで実行できます（ルート権限で実行する必要があります）:

```bash
sudo raspi-config
```

すると以下のようなインターフェースが表示されます:

raspi-config

`obcam` を使用するためには、以下の設定が必要になります：

1. WiFi 設定
2. 「legacy camera support」を有効化

!!!note "設定後の再起動"
    `raspi-config` での設定変更の多くは再起動を要求しますので、フライトカメラモードの実行前には再起動をしておく必要があります。

### WiFi 設定

`raspi-config` インターフェース上で、

1. *System Options* を選択。
2. *Wireless LAN* を選択。
3. 国/地域を選択 (e.g. *JP Japan*)。
4. SSID を入力。
5. パスワードを入力。

!!!info "テザリング"
    スマートフォンによるテザリングは多くの場合 WiFi のアクセスポイント兼ルーターとしての良い選択の1つです。テザリングを利用する場合は、その SSID とパスワードを上記の設定時に入力してください。

### 「legacy camera support」の有効化

`raspi-config` インターフェース上で、

1. *Interface Options* を選択。
2. *Legacy Camera* を選択。
3. *Yes* を選択。
4. *OK* を選択。

!!!info "Legacy camera support"
    Raspberrry Pi OS の最新版では `libcamera` を使ったカメラインターフェースが採用されており、以前から使われていたレガシーなカメラサポートは非推奨になっています。しかし Raspberry Pi Camera の制御のために `obcam` で使用している `picamera` という Python モジュールは、このレガシーなカメラインターフェースを使用しています。それが理由で「legacy camera support」を有効化する必要があります。

## フライトカメラモードの簡単設定

この方法を用いると `obcam` のインストールおよびフライトカメラモードの有効化を同時に行うことが出来ます。この簡単設定は[リポジトリ上](https://github.com/FROM-THE-EARTH/obcam/blob/main/install.sh) `install.sh` を実行することで行えます。詳細が気になる場合は[こちらのセクション](#_7)を参照してください。

まずは `git clone` を使用してリポジトリをダウンロードします（ネットワーク環境が必要です）：

```bash
git clone https://github.com/FROM-THE-EARTH/obcam.git
```

その後、簡単設定を行うことが出来ます：

```bash
cd obcam
sudo ./install.sh
```

これで `obcam` のフライトカメラモードの有効化は完了です。次に起動されるときからフライトカメラモードでプログラムが自動実行されます。

!!!info "`git` のインストール"
    もし `git` がインストールされていなければ、以下のようにして `git` をインストール出来ます：

    ```bash
    sudo apt update
    sudo apt install git
    ```

## `obcam` モジュールのみのインストール

`obcam` は `pip` を使用してインストール出来ます。

```bash
pip install git+https://github.com/FROM-THE-EARTH/obcam.git
```

インストール後、フライトカメラプログラムを実行する `obcam` コマンドが使用可能になります。

!!!info "`pip` がインストールされていない場合"
    Raspberry Pi の最初の起動直後は `pip` がインストールされていない可能性があります。このような場合、以下の方法で `pip` をインストール出来ます。

    1. まずは `pip` をインストールするためのスクリプトをダウンロードします。以下のコマンドの実行後、`get-pip.py` というスクリプトがカレントディレクトリにダウンロードされます。
        ```bash
        wget https://bootstrap.pypa.io/get-pip.py
        ```
    2. `get-pip.py` を実行します。
        ```bash
        python get-pip.py
        ```

## フライトカメラモードの有効化

### フライトカメラモードについて

フライトカメラモードでは、フライトカメラプログラムは Raspberrry Pi の起動時に自動実行されます。フライトカメラモードを有効化は、以下の手順で行えます：

1. [ネットワークとカメラ設定](#raspi-config)
2. [`obcam` のインストール](#obcam)
3. [gileum ファイルを書く](#gileum)
4. [フライトカメラモードのみの有効化](#_6)

### gileum ファイルを書く

gileum ファイルはこのアプリケーションの設定ファイルのようなものです。`glm.py` は1つの gileum ファイルであり、フライトカメラモードの有効化前に設定しておく必要があります。`glm.py` はリポジトリ直下においてあり、ダウンロード後に上書きして利用できます。設定パラメータの詳細については[こちらのページ](./setting.md)を参照してください。ただし、設定パラメーターはダウンロード時に最適な値に設定されているため、**デバッグなどの理由がない限りパラメーターを変更する必要はありません**。

### フライトカメラモードのみの有効化

`scripts/activate_flightcam.sh` というスクリプトを使用すれば、フライトカメラモードのみを有効化できます。`scripts/activate_flihgtcam.sh` は[リポジトリ上](https://github.com/FROM-THE-EARTH/obcam/blob/main/scripts/activate_flightcam.sh)に置いてあります。

```bash
sudo ./scripts/activate_flightcam.sh
```

## `obcam` のアップデート

### `obcam` のみのアップデート

以下のコマンドで `pip` を使用してアップデートできます：

```bash
pip install --upgrade git+https://github.com/FROM-THE-EARTH/obcam.git
```

### `obcam` のアップデートおよびフライトカメラモードの有効化

1. ローカルリポジトリの削除：
    ```bash
    rm -rf obcam/
    ```
2. [こちらのセクション](#_3)にしたがって再度フライトカメラモードを有効化

## フライトカメラモードの有効化の詳細

ここではフライトカメラモードの有効化のプロセスについて説明します。そのプロセス自体はそこまで複雑ではありません。ポイントは `/etc/rc.local` を設定するという点です。 `/etc/rc.local` はシェルスクリプトであり、OS の起動時に自動実行されるスクリプトです。

`scripts/activate_flightcam.sh` というスクリプトは `/etc/rc.local` に `obcam` プログラムを実行される以下の一行を挿入します:

```
# /etc/rc.local

# Some lines ...

/usr/bin/python -m obcam /usr/local/src/obcam/glm.py
exit 0
```

上のコードからわかるように、フライトカメラモードでは `/usr/local/src/obcam/glm.py` という `scripts/activate_flightcam.sh` が実行された際にコピーされた gileum ファイルを使用して実行されます。したがって、コピー前の gileum ファイルであるダウンロードしたリポジトリ下にある `glm.py` の内容を変更しても、フライトカメラモードの実行には影響がありません。もし gileum ファイルの内容を変更してフライトカメラモードを実行したい場合は、 `/usr/local/src/obcam/glm.py` を直接修正するか、リポジトリ下にある `glm.py` を `/usr/local/src/obcam/glm.py` に再度コピーしてください。

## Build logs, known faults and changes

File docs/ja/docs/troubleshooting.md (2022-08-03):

# トラブルシューティング

## SD カードが壊れた場合

1. PC にその SD カードを差し込んでください。
2. [このセクション](./setup.md#os)を参考にして OS イメージの再書き込みを行ってみてください。もし書き込みが出来なかった場合は、新しい SD カードに交換する必要があります。

## カメラが検知されない場合

1. [こちらのセクション](./setup.md#legacy-camera-support)を参考にして「legacy camera support」が有効になっているかどうか確認してください。
2. カメラケーブルが正しく接続されているか確認してください。
3. これらの方法でも問題が解消されない場合、カメラもしくは Raspberrry Pi を交換する必要がある可能性があります。

## フライトカメラモードを有効化しても `obcam` が正常に実行されない場合

1. モニターとキーボードを Raspberry Pi に接続し、 `obcam` のログ出力を確認してください。
2. ターミナル上で `obcam` を実行し、反応を確認してください。
    ```bash
    sudo obcam /usr/local/src/obcam/glm.py
    ```
3. `obcam` がインストールされていない場合、 [こちらのセクション](./setup.md#_3)を参考にして `obcam` をインストールし、フライトカメラモードを有効化してください。
4. もしこの方法でも `obcam` が上手く動作しない場合、フライトカメラモードが有効化されていない場合があります。以下のコマンドでフライトカメラモードを有効化してください：
    ```bash
    sudo /usr/local/src/obcam/scripts/activate_flightcam.sh
    ```
5. 上記の操作で `/usr/local/src/obcam/glm.py` がないという出力が出た場合、フライトカメラモードが1度も有効化されたことがない可能性があります。`git clone` でダウンロードしたリポジトリ下にある `scripts/activate_flightcam.sh` を実行してください：
    ```bash
    sudo ./scripts/activate_flightcam.sh
    ```

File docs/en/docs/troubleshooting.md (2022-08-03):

# Trouble Shooting

## When SD cards are broken

1. Insert a broken SD card to your PC.
2. If possible, clean up and rewrite the OS image referencing [the section](./setup.md#setup-of-the-os). If the trial fails, you should use new SD card and write in the OS image to the SD card.

## When camera is not detected

1. Confirm if legacy camera support is enabled or not, referencing [the section](./setup.md#enabling-legacy-camera-support).
2. Confirm if camera cable is connected properly or not.
3. If the trouble is not solved in spite of the operations above, change camera or Raspberry Pi.

## When `obcam` doesn't work regardless of activation of the flight camera mode

1. Connect a monitor and keyboard to the Raspberry Pi and check log output from `obcam`.
2. Execute `obcam` in the terminal and check the response.
    ```bash
    sudo obcam /usr/local/src/obcam/glm.py
    ```
3. If `obcam` is not installed, install `obcam` and activate the flight camera mode, referencing [the section](./setup.md#brief-setup-for-the-flight-camera-mode).
4. If `obcam` successfully run in this way, it is possible that the flight camera mode is deactivated. Thus, activate the flight camera mode:
    ```bash
    sudo /usr/local/src/obcam/scripts/activate_flightcam.sh
    ```
5. If the shell tells you that `/usr/local/src/obcam/glm.py` doesn't exist, it is possible that the flight camera mode have never been activated. Thus, activate the flight camera mode:
    ```bash
    sudo /usr/local/src/obcam/scripts/activate_flightcam.sh
    ```

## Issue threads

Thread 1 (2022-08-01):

Implement some commands using flight pin.

jjj999, 2022-08-01:
## Context

- Now the flight camera application doesn't make a Raspberry Pi shut down. However, it could be ideal to shut a Raspberrry Pi down for safety of the SD card.
- Shuting down by the program causes not to start a shell session. Therefore, some commands, including the process that exits the program immidiately before shutting down, are required.
- During assembly of the rocket, it is possible to pull a flight pin out because of some troubles. Thus, the command that restarts the program is required.

## Steps

- [x] Add the process that shuts down system after recording.
- [x] Implement the command that exits the program before shutting down.
- [x] Implement the command that restarts the program during recording.
- [x] Reflect the chage of source code to the documentation.

jjj999, 2022-08-02:
Approved the PR #11 .

Closed 2022-08-02.

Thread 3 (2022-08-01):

Improve recording quality.

jjj999, 2022-08-01:
## Context

- In the source code and settings, recorded movie is stacked, not smooth, if the program is ran in a Raspberry Pi Zero.

## Steps

- [x] Improve performance of writing video into a file.
- [x] Add some parameters affecting performance of recording, e.g. framerate.

jjj999, 2022-08-01:
Actually no such a stack of movie exist. Thus, the current source code doesn't give performance harmful effects.

jjj999, 2022-08-01:
Approved the PR #4 .

Closed 2022-08-01.

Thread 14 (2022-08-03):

Enhance the documentation especially about operations.

jjj999, 2022-08-03:
## Context

- The current documentation is not sufficient when operators of `obcam` have some troubles, because the documentation tells only specification and operations in successful conditions.
- To enable to handle troubles which occur in a rocket range, the documentation should have trouble shooting and checklist of operations.

## Steps

- Add trouble shooting:
  - [x] Case where SD cards are broken
  - [x] Case where camera is not detected
  - [x] Case where `obcam` doesn't work by unknown reason
- [x] Add checklist of operations.
- Add how to extract data from SD cards used in Raspberry Pi.
  - [x] To use 3rd party application.
  - [x] To transfer via HTTP.
  - [x] To transfer via SSH.
- [x] Add how to convert video format from H264 to MP4.
- [ ] Revise the README.

jjj999, 2022-08-03:
Approved the PR #15 .

Closed 2022-08-03.

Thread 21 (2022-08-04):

Extend size of swap before recording.

jjj999, 2022-08-04:
## Context

- Recording for a long time could cause lask of memory and the system will be frozen, outputing
  ```
  Unable to handle kernel paging request at virtual address xxxxxxxx
  ```
- To solve the problem, swap memory should be expanded (default size 100MB in Raspberry Pi OS Lite).

## Steps

- [ ] Add the script that expands swap memory to 2GB.

jjj999, 2022-08-04:
Approved the PR #22 .

Closed 2022-08-04.

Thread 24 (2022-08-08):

Improve CPU-bound processes for performance.

jjj999, 2022-08-08:
## Context

- In the current source code, waiting process for disconnection of a flight pin is CPU-bound.
- We should improve such processes to suppress battery consumption.

## Steps

1. Change the source code without while loops as well as possible.

jjj999, 2022-08-08:
Approved the iss #25 .

Closed 2022-08-08.

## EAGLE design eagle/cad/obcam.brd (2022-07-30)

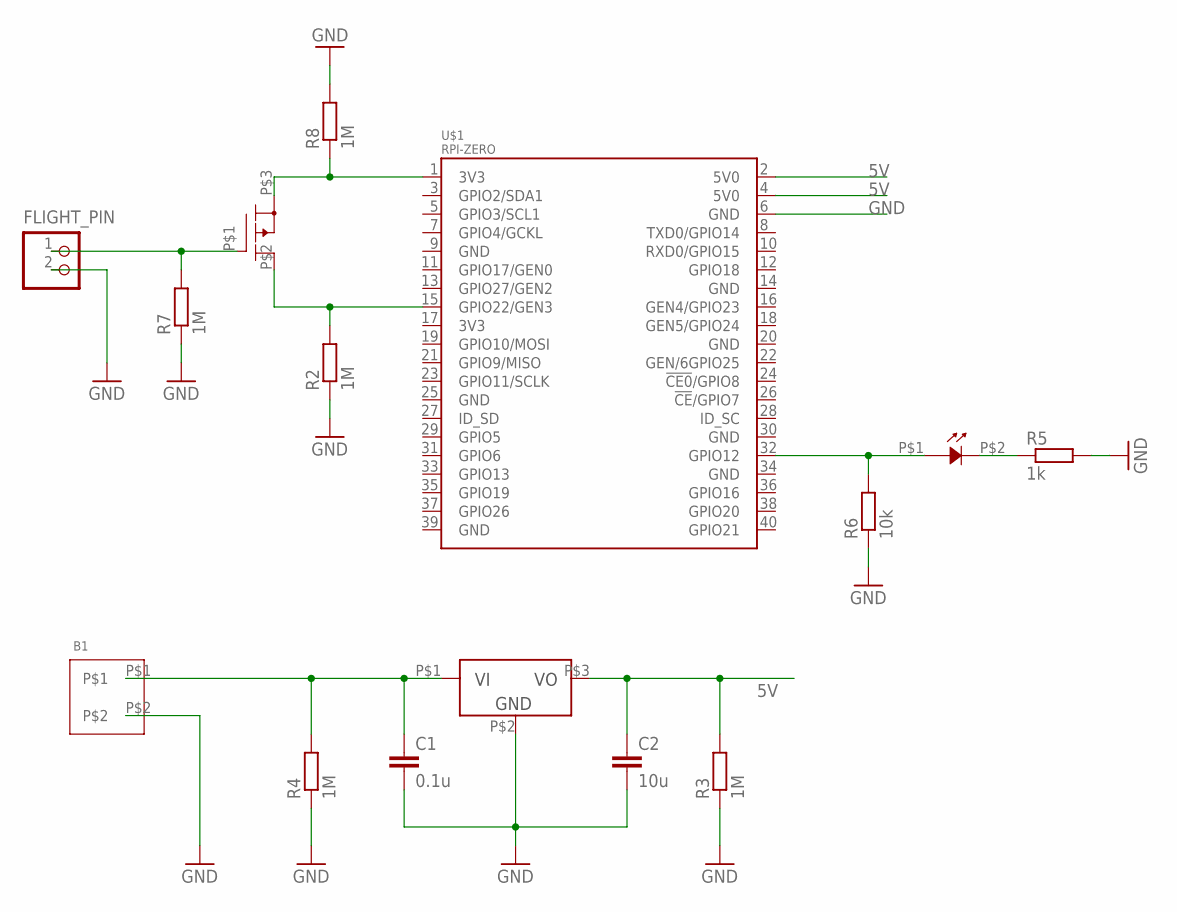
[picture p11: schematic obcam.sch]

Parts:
B1: 9V_BATTERY_HOLDER
C1: 0.1u; C2012
C2: 10u; C2012
D1: SML-E1X
FLIGHT_PIN: B2B-XH-A
IC1: NJM2391; TO252
IC2: TJ8S06M3L; TO252
R2, R3, R4, R7, R8: 1M; M2012
R5: 1k; M2012
R6: 10k; M2012
U$1: RPI-ZERO; RASP_PI_ZERO_BOARD_FULL

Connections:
3V3@1: IC2.P$3, R8.1, U$1.1 (3V3)
5V: C2.1, IC1.P$3, R3.2, U$1.2 (5V0), U$1.4 (5V0)
FLIGHT_IO: IC2.P$2, R2.2, U$1.15 (GPIO22/GEN3)
GND: B1.P$2, C1.2, C2.2, FLIGHT_PIN.2, IC1.P$2, R2.1, R3.1, R4.1, R5.2, R6.1, R7.1, R8.2, U$1.6 (GND)
unnamed: B1.P$1, C1.1, IC1.P$1, R4.2
unnamed: FLIGHT_PIN.1, IC2.P$1, R7.2
unnamed: D1.P$2, R5.1
unnamed: D1.P$1, R6.2, U$1.32 (GPIO12)

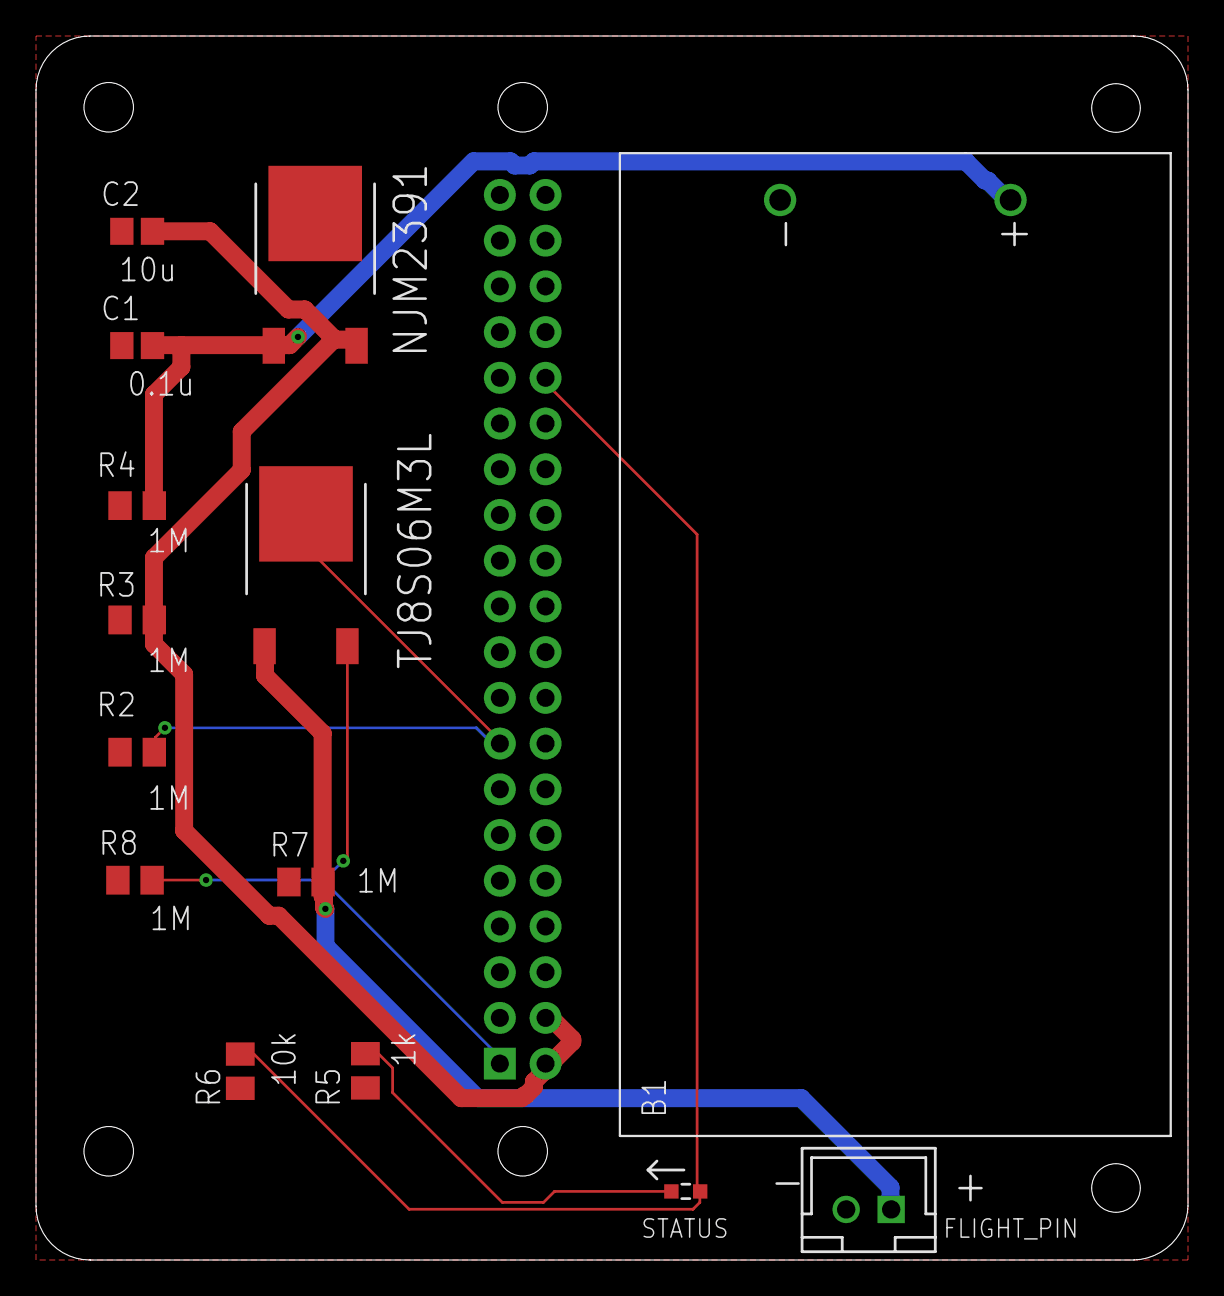
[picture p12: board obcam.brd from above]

Board: 2 copper layers, 64.0 x 68.0 mm, 15 parts (1 on the bottom side), 8 nets.

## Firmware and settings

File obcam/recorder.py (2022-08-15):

from __future__ import annotations
import enum
import logging
import os
import time
import threading
import typing as t

import picamera
import RPi.GPIO as gpio

from .util import get_timestamp


_VIDEO_FORMATS = {
    "h264",
    "mjpeg",
    "yuv",
    "rgb",
    "rgba",
    "bgr",
    "bgra",
}


def verify_video_format(path: str) -> bool:
    ext = os.path.splitext(path)[1]
    if not len(ext):
        return False
    return ext[1:] in _VIDEO_FORMATS


class Command(enum.Enum):
    """Command list of the application."""

    RESTART = enum.auto()
    """Command to restart recording."""

    EXIT = enum.auto()
    """Command to stop recording and exit immediately before shutting down."""

    NULL = enum.auto()
    """Represents no commands activated."""


GRACE_PERIOD_FOR_CHATTERING = 0.3     # seconds


class IORecorder:

    def __init__(
        self,
        pin_flight: int,
        pin_led: int,
        logger: logging.Logger,
        resolution: t.Tuple = (1920, 1080),
        framerate: int = 30,
        led_blink_freq: float = 2.,
    ) -> None:
        """
        Args:
            pin_flight: Pin number for a flight pin.
            pin_led: Pin number for a status LED.
            logger: Logger for the flight camera.
            resolution: Resolution of the video.
            framerate: Framerate of the video.
            led_blink_freq: Frequency of LED blinking.
        """
        self._logger = logger
        try:
            self._camera = picamera.PiCamera(
                resolution=resolution,
                framerate=framerate,
            )
        except picamera.PiCameraMMALError as e:
            self._logger.exception(
                "Failed to enable camera connection. Please confirm "
                "camera connection or camera setting, referencing "
                "https://from-the-earth.github.io/obcam/troubleshooting/"
                "#when-camera-is-not-detected .",
                exc_info=e,
            )
            raise e

        self._first_recording = True

        self._pin_flight = pin_flight
        self._pin_led = pin_led

        self._lock_in_recording = threading.RLock()
        self._in_recording = False

        self._lock_command = threading.RLock()
        self._command = Command.NULL

        self._lock_flightpin_onoff = threading.RLock()
        self._flightpin_onoff: t.List[t.List[bool, float]] = []

        gpio.setmode(gpio.BCM)
        gpio.setup(self._pin_flight, gpio.IN, pull_up_down=gpio.PUD_DOWN)
        gpio.setup(self._pin_led, gpio.OUT)

        self._pwm_led = gpio.PWM(self._pin_led, led_blink_freq)
        self._pwm_led.start(0)

    def __del__(self) -> None:
        try:
            self._camera.stop_recording()
            self._pwm_led.stop()
        except AttributeError:
            pass
        else:
            gpio.cleanup()
            self._logger.debug("Cleaned up the all GPIO pins.")

    @property
    def in_flight(self) -> bool:
        """If the body is in flight or not."""
        return (gpio.input(self._pin_flight) == 1)

    def blink_led(self) -> None:
        self._pwm_led.ChangeDutyCycle(50)
        self._logger.debug("LED started to be blinking.")

    def turn_on_led(self) -> None:
        self._pwm_led.ChangeDutyCycle(100)
        self._logger.debug("Turned the LED on.")

    def turn_off_led(self) -> None:
        self._pwm_led.ChangeDutyCycle(0)
        self._logger.debug("Turned the LED off.")

    def _log_waiting_time(self, interval: float = 1.) -> None:
        time_init = time.time()
        while True:
            with self._lock_in_recording:
                if self._in_recording:
                    break

            self._logger.debug(
                "Waiting the flight pin to be disconnected, "
                f"{round(time.time() - time_init, 3)} elapsing."
            )
            time.sleep(interval)

    def _watch_flightpin(self, interval: float = 0.1) -> None:
        time_init = None
        last_level = None
        while True:
            with self._lock_in_recording:
                if not self._in_recording:
                    return

            level = self.in_flight
            with self._lock_flightpin_onoff:
                if last_level is None or level != last_level:
                    time_init = time.time()
                    self._flightpin_onoff.append([level, 0.])
                else:
                    self._flightpin_onoff[-1][1] = time.time() - time_init

            last_level = level
            time.sleep(interval)

    def _watch_commands(
        self,
        interval: float = 0.1,
        threshold_restart: float = 5.,
        threshold_exit: float = 2.,
    ) -> None:
        while True:
            with self._lock_in_recording:
                if not self._in_recording:
                    return

            with self._lock_flightpin_onoff:
                for i, (level, time_) in enumerate(self._flightpin_onoff):
                    if level:
                        continue

                    if time_ >= threshold_restart:
                        with self._lock_command:
                            self._command = Command.RESTART
                            return
                    elif GRACE_PERIOD_FOR_CHATTERING < time_ <= threshold_exit:
                        try:
                            if self._flightpin_onoff[i + 1][1] < threshold_exit:
                                continue

                            with self._lock_command:
                                self._command = Command.EXIT
                                return
                        except IndexError:
                            pass

            time.sleep(interval)

    def _wait_until_flightpin_connected(self) -> None:
        if not self.in_flight:
            return

        while True:
            gpio.wait_for_edge(self._pin_flight, gpio.FALLING)

            self._logger.debug(
                "Disconnection of the flight pin was detected. "
                f"Waiting {GRACE_PERIOD_FOR_CHATTERING} seconds to verify "
                "the flight pin was pulled out exactly."
            )
            time_init = time.time()
            is_flightpin_connected = False
            while True:
                if self.in_flight:
                    self._logger.debug(
                        "Level of the flight pin is high. It means that "
                        "the flight pin is disconnected before time of "
                        "waiting threshold elapsed. Thus, detecting "
                        "the flight pin is to be continued."
                    )
                    break
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

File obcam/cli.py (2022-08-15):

import logging
import os
from os.path import (
    isdir,
    join,
)

import click
import gileum

from .glm import OBCamGileum
from .recorder import (
    Command,
    IORecorder,
)
from .util import (
    get_timestamp,
    shutdown_now,
)


LOG_PLACEHOLDER = "[%(asctime)s] [%(levelname)s] %(message)s"


def run_flight_camera(glm: OBCamGileum) -> None:
    # Setup the logger.
    if glm.file_log is None:
        file_log = get_timestamp("mov", "log")
    if glm.parent_dir is not None:
        if not isdir(glm.parent_dir):
            os.makedirs(glm.parent_dir)
        file_log = join(glm.parent_dir, file_log)

    handler = logging.FileHandler(file_log)
    handler.setLevel(glm.log_level)
    handler.setFormatter(logging.Formatter(LOG_PLACEHOLDER))
    logger = logging.getLogger()
    logger.setLevel(glm.log_level)
    logger.addHandler(handler)

    logger.info(
        "Start the Flight camera mode. "
        f"Setting; {', '.join([f'{k}: {v}' for k, v in glm.dict().items()])}"
    )

    try:
        recorder = IORecorder(
            glm.pin_flight,
            glm.pin_led,
            logger,
            resolution=glm.resolution,
            framerate=glm.framerate,
            led_blink_freq=glm.led_blink_freq,
        )

        while True:
            # Setup file paths.
            if glm.file_mov is None:
                file_mov = get_timestamp("mov", "h264")
            if glm.parent_dir is not None:
                file_mov = join(glm.parent_dir, file_mov)

            # Start recording.
            command = recorder.record(
                glm.timeout,
                file_mov=file_mov,
                interval_recording=glm.interval_recording,
                check_waiting_time=glm.check_waiting_time,
                interval_waiting_time=glm.interval_waiting_time,
                interval_watching=glm.interval_watching,
                threshold_restart=glm.threshold_restart,
                threshold_exit=glm.threshold_exit,
            )
            if command is Command.EXIT:
                break
            if command is Command.RESTART:
                continue
            else:
                break
    except Exception as e:
        logger.exception("Finish with an exception.", exc_info=e)
        raise e
    else:
        if glm.shutdown_after_recording and command is Command.NULL:
            logger.info("Shut down the system.")
            shutdown_now()


@click.command()
@click.argument(
    "glm_file",
    type=click.Path(exists=True),
)
def main(glm_file: str) -> None:
    gileum.load_glms_at(glm_file)
    glm = gileum.get_glm(OBCamGileum)

    run_flight_camera(glm)

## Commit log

2022-07-30 first commit.
    [obcamera.brd, obcamera.sch]
2022-07-30 Changed the flight pin level logic.
2022-07-30 Took noise measures when detecting a flight pin to be connected.
    [recorder.py]
2022-07-30 Fixed a bug aboout noise measures.
    [recorder.py]
2022-07-30 Added another command for activating camera
2022-07-30 Fixed the library of TJ8S06M3L and updated CAD.
    [obcam.brd, obcam.sch]
2022-07-30 Removed an useless line for activation of camera
2022-07-31 Took a measure for stop of power supply.
2022-08-01 Added new parameter `framerate`. #3
2022-08-01 Fixed a type. #3
    [glm.py]
2022-08-01 Fixed the bug that fails format validation of video files. #3
    [recorder.py]
2022-08-02 Changed to run recording in the main thread. #8
2022-08-02 Changed the logic of waiting connection of a flight pin. #1
2022-08-03 Added description about enabling legacy camera support.
2022-08-03 Reflected the current application flow to the flowchart.
2022-08-03 Updated description about assembly and flow of the program.
2022-08-03 Fixed the bug that causes deadlock of `lock_in_recording`.
    [recorder.py]
2022-08-03 Fixed bug that shuts down when the command EXIT is activated.
    [cli.py]
2022-08-04 Updated the flowchart so that includes descriptions about status LED.
2022-08-08 Revised the code of waiting until a flight pin connected not to be CPU-bound. #24
2022-08-15 Fixed bug that raises `AttributeError` if camera is not detected.
    [recorder.py]
2022-08-15 Made log outputs more detail when camera connection is disabled.
